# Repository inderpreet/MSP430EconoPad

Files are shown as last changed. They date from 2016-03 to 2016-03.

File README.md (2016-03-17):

MSP430 G Series Econo Launchpad
===============================
This is the PCB design for the TI MSP430 Economy Launchpad. It fits in a 5cm x 5xm area and does not include the programmer. You can buy an official launchpad and then use this to make standalone Launchpads. This is NOT the official design but rather my version.

The project is at www.github.com/inderpreet/MSP430Econopad

Format is EagleCAD schematic and board layout

For more details, check out the website at

-----> http://embeddedcode.wordpress.com

## Support
I would love your support and currently I am not able accept any donations. Just give a shout out to me at www.twitter.com/ip_v1 and help with documentation of this project and I will be very thankful. Enjoy the board.

###Designed by Inderpreet Singh Of Guru Nanak Dev Univeristy, Amritsar

This software may be distributed and modified under the terms of the GNU
General Public License version 2 (GPL2) as published by the Free Software
Foundation and appearing in the file LICENSE.TXT included in the packaging of
this file. Please note that GPL2 Section 2[b] requires that all works based
on this software must also be made publicly available under the terms of
the GPL2 ("Copyleft").

We put a lot of time and effort into our project and hence this copyright 
notice ensures that people contribute as well as each contribution is 
acknowledged. Please retain this original notice and if you make changes
please document them below along with your details.

The latest copy of this project/library can be found at: 
https://github.com/inderpreet/

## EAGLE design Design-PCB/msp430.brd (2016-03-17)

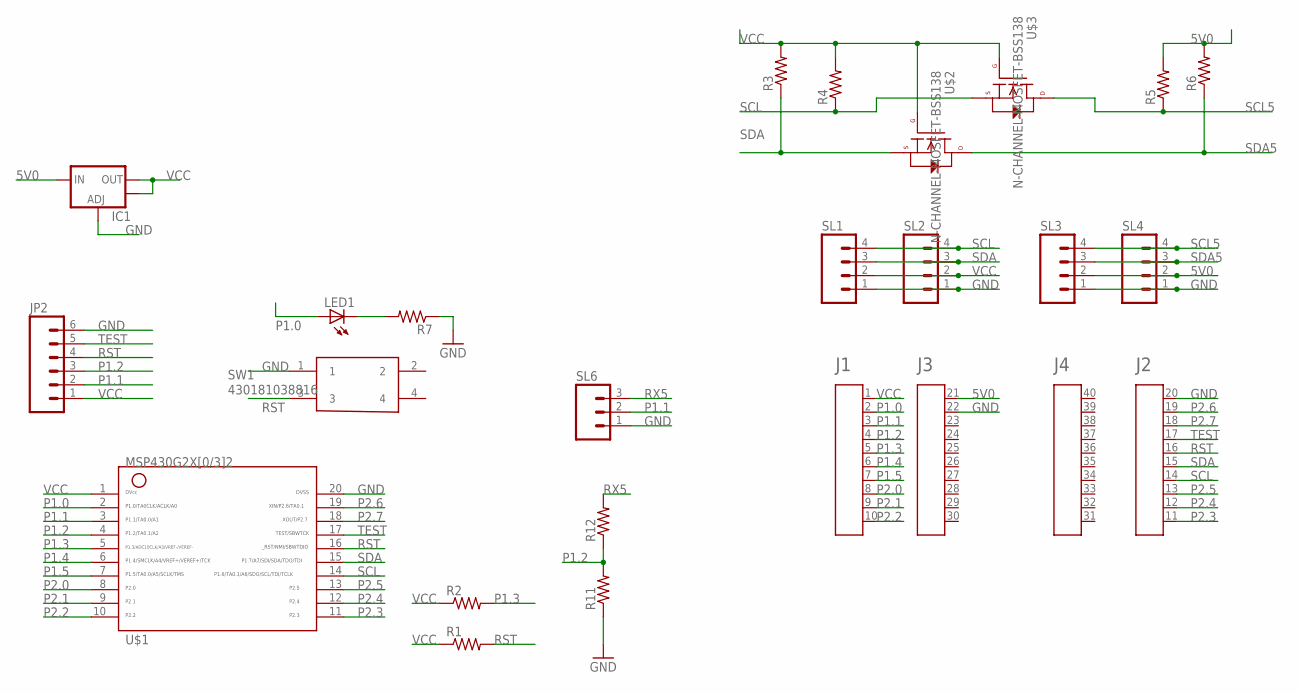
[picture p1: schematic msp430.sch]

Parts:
A1: HEADER4X10-BOOSTERPACK; 4X10-BOOSTERPACK
IC1: V_REG_LM1117SOT223; SOT223
JP2: M06LOCK; 1X06_LOCK
LED1: LEDCHIPLED_0805; CHIPLED_0805
R1, R2, R3, R4, R5, R6, R7, R11, R12: R-US_M0805; M0805
SL1, SL2, SL3, SL4: M04; 04P
SL6: M03; 03P
SW1: 430181038816
U$1: G2X[0/3]2---N20; N20
U$2, U$3: N-CHANNEL-MOSFET-BSS138; SOT23-3

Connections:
5V0: A1.21, IC1.3 (IN), R5.2, R6.2, SL3.2, SL4.2
GND: A1.20, A1.22, IC1.1 (ADJ), JP2.6, R7.1, R11.1, SL1.1, SL2.1, SL3.1, SL4.1, SL6.1, SW1.1, U$1.20
unnamed: LED1.C, R7.2
P1.0: A1.2, LED1.A, U$1.2
P1.1: A1.3, JP2.2, SL6.2, U$1.3
P1.2: A1.4, JP2.3, R11.2, R12.1, U$1.4
P1.3: A1.5, R2.2, U$1.5
P1.4: A1.6, U$1.6
P1.5: A1.7, U$1.7
P2.0: A1.8, U$1.8
P2.1: A1.9, U$1.9
P2.2: A1.10, U$1.10
P2.3: A1.11, U$1.11
P2.4: A1.12, U$1.12
P2.5: A1.13, U$1.13
P2.6: A1.19, U$1.19
P2.7: A1.18, U$1.18
RST: A1.16, JP2.4, R1.2, SW1.3, U$1.16
RX5: R12.2, SL6.3
SCL: A1.14, R4.1, SL1.4, SL2.4, U$1.14, U$3.2 (S)
SCL5: R5.1, SL3.4, SL4.4, U$3.3 (D)
SDA: A1.15, R3.1, SL1.3, SL2.3, U$1.15, U$2.2 (S)
SDA5: R6.1, SL3.3, SL4.3, U$2.3 (D)
TEST: A1.17, JP2.5, U$1.17
VCC: A1.1, IC1.2 (OUT), IC1.4 (OUT), JP2.1, R1.1, R2.1, R3.2, R4.2, SL1.2, SL2.2, U$1.1, U$2.1 (G), U$3.1 (G)

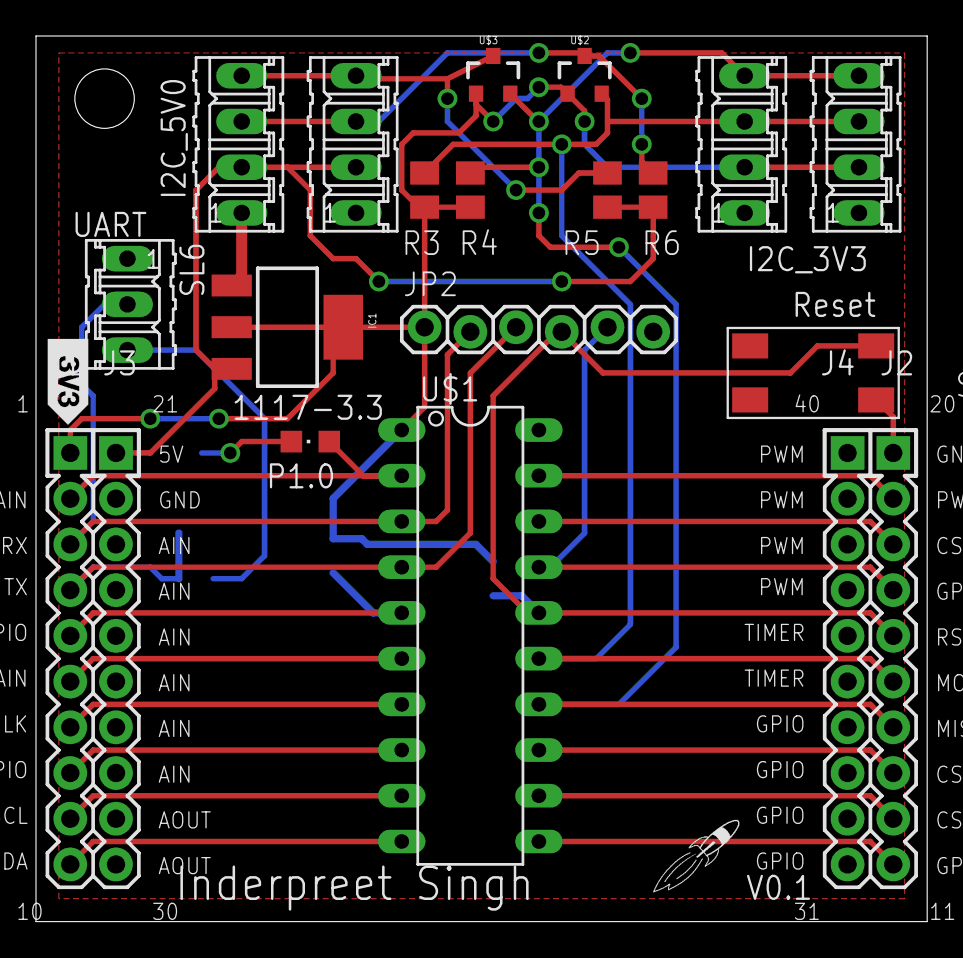
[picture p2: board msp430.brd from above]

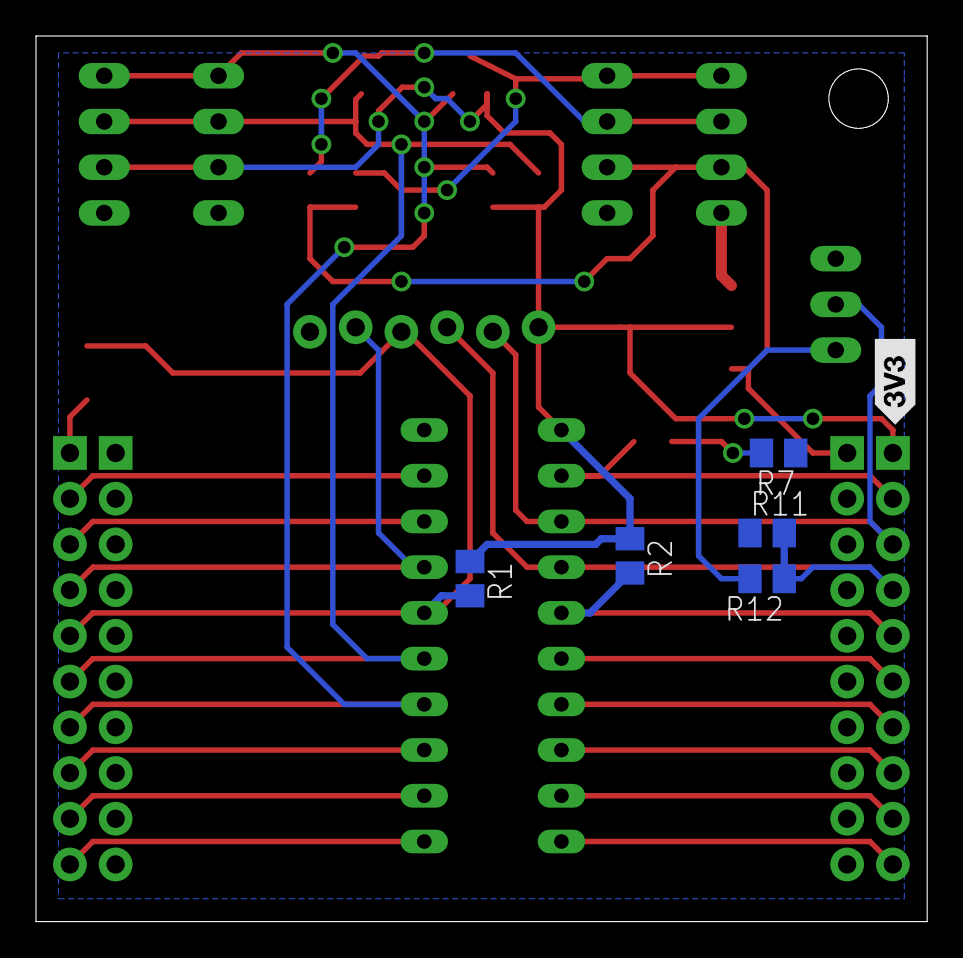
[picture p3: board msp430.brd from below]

Board: 2 copper layers, 49.5 x 49.2 mm, 25 parts (5 on the bottom side), 25 nets.

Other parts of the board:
U$4: STAND-OFF
U$5: SILK_3V3_TAG
U$6: LOGO-ROCKET

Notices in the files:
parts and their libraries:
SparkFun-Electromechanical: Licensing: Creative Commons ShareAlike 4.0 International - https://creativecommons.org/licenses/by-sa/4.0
